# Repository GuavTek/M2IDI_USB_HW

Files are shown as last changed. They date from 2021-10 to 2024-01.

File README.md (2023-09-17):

This eurorack module connects MIDI over USB with the internal MIDI bus, and will work in both USB device and host modes. It also offers stereo audio streaming into and out from the rack when running in device mode. 
View this project on [CADLAB.io](https://cadlab.io/project/25232) to see renders of schematics and PCBs, as well as current issues. 

<h2> A part of the M2IDI prototypes </h2>

<p>
The code for this module can be found on  
<a href="https://github.com/GuavTek/M2IDI_USB">
			  GitHub
		  </a>
</p>

<p> 
More info on the M2IDI system can be found on the 
<a href="https://hackaday.io/project/182092-modular-midi">
			  Hackaday project page
		  </a>

</p>

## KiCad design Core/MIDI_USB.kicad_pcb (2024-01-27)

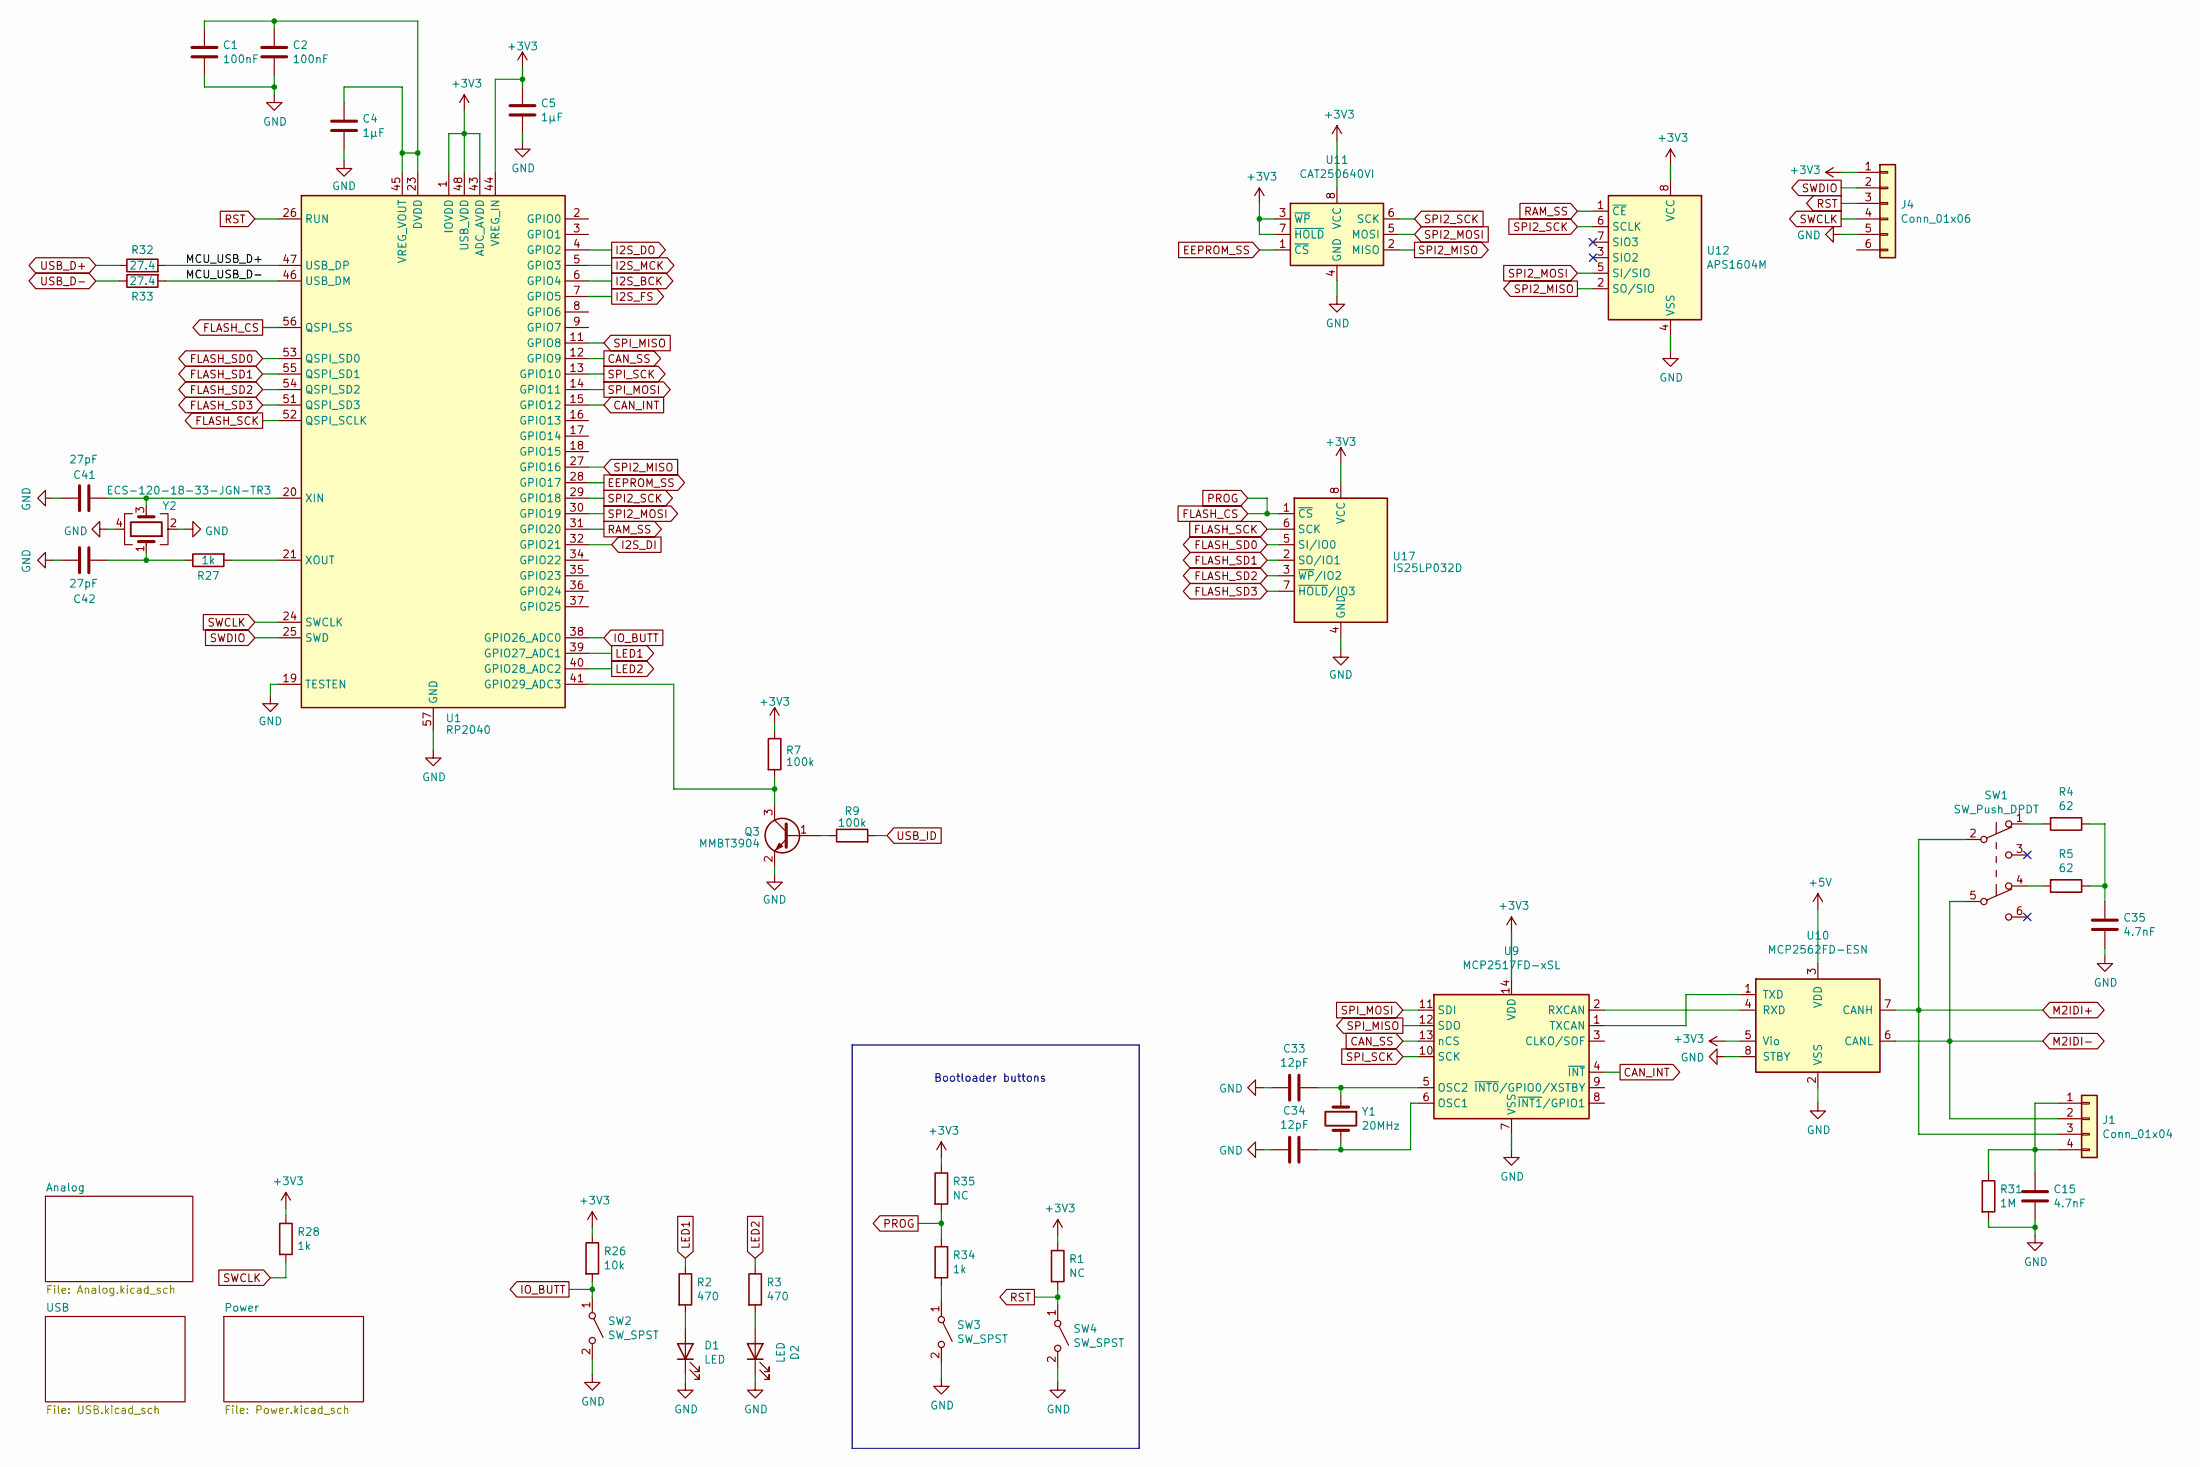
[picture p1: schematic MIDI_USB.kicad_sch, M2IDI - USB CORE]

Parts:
C1, C2: 100nF; C_0603_1608Metric
C4, C5: 1µF; C_0603_1608Metric
C15, C35: 4.7nF; C_0603_1608Metric
C33, C34: 12pF; C_0603_1608Metric
C41, C42: 27pF; C_0603_1608Metric
D1: LED; LED_D3.0mm_Horizontal_O1.27mm_Z2.0mm
D2: LED; LED_D3.0mm_Horizontal_O3.81mm_Z2.0mm
J1: Conn_01x04; MicroMatch_04_Angled
J4: Conn_01x06; PinHeader_2x03_P2.54mm_Vertical_SMD
Q3: MMBT3904; SOT-23
R1, R35: NC; R_0603_1608Metric
R2, R3: 470; R_0603_1608Metric
R4, R5: 62; R_0805_2012Metric
R7, R9: 100k; R_0603_1608Metric
R26: 10k; R_0603_1608Metric
R27, R28, R34: 1k; R_0603_1608Metric
R31: 1M; R_0603_1608Metric
R32, R33: 27.4; R_0603_1608Metric
SW1: SW_Push_DPDT; SlideDPDT_JS202011
SW2: SW_SPST; SW_Tactile_SPST_Angled_PTS645Vx58-2LFS
SW3, SW4: SW_SPST; SW_SPST_B3U-1000P
U1: RP2040; QFN-56-1EP_7x7mm_P0.4mm_EP3.2x3.2mm
U9: MCP2517FD-xSL; SOIC-14_3.9x8.7mm_P1.27mm
U10: MCP2562FD-ESN; SOIC-8_3.9x4.9mm_P1.27mm
U11: CAT250640VI; SOIC-8_3.9x4.9mm_P1.27mm
U12: APS1604M; SOIC-8_3.9x4.9mm_P1.27mm
U17: IS25LP032D; SOIC-8_3.9x4.9mm_P1.27mm
Y1: 20MHz; Crystal_2pin_2.0x2.5mm
Y2: ECS-120-18-33-JGN-TR3; Crystal_SMD_3225-4Pin_3.2x2.5mm_HandSoldering

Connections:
+3V3: C5.1, J4.1, R1.1, R7.1, R26.1, R28.1, R35.1, U1.1 (IOVDD), U1.10 (IOVDD), U1.22 (IOVDD), U1.33 (IOVDD), U1.42 (IOVDD), U1.43 (ADC_AVDD), U1.44 (VREG_IN), U1.48 (USB_VDD), U1.49 (IOVDD), U9.14 (VDD), U10.5 (Vio), U11.3 (~WP), U11.7 (~HOLD), U11.8 (VCC), U12.8 (VCC); also elsewhere on the board
/MCU_USB_D+: R32.2, U1.47 (USB_DP); also elsewhere on the board
/MCU_USB_D-: R33.2, U1.46 (USB_DM)
CAN_INT: U1.15 (GPIO12), U9.4 (~INT)
CAN_SS: U1.12 (GPIO9), U9.13 (nCS)
EEPROM_SS: U1.28 (GPIO17), U11.1 (~CS)
FLASH_CS: R34.1, R35.2, U1.56 (QSPI_SS); also elsewhere on the board
FLASH_SCK: U1.52 (QSPI_SCLK); also elsewhere on the board
FLASH_SD0: U1.53 (QSPI_SD0); also elsewhere on the board
FLASH_SD1: U1.55 (QSPI_SD1); also elsewhere on the board
FLASH_SD2: U1.54 (QSPI_SD2); also elsewhere on the board
FLASH_SD3: U1.51 (QSPI_SD3); also elsewhere on the board
I2S_BCK: U1.6 (GPIO4); also elsewhere on the board
I2S_DI: U1.32 (GPIO21); also elsewhere on the board
I2S_DO: U1.4 (GPIO2); also elsewhere on the board
I2S_FS: U1.7 (GPIO5); also elsewhere on the board
I2S_MCK: U1.5 (GPIO3); also elsewhere on the board
IO_BUTT: R26.2, SW2.1 (A), U1.38 (GPIO26_ADC0)
LED1: R2.1, U1.39 (GPIO27_ADC1)
LED2: R3.1, U1.40 (GPIO28_ADC2)
M2IDI+: J1.3, SW1.2 (B), U10.7 (CANH)
M2IDI-: J1.2, SW1.5 (B), U10.6 (CANL)
unnamed: C35.1, R4.1, R5.1
unnamed: C42.1, R27.1, Y2.1
unnamed: D1.2 (A), R2.2
unnamed: D2.2 (A), R3.2
unnamed: C15.1, J1.1, J1.4, R31.1
unnamed: Q3.1 (B), R9.1
unnamed: Q3.3 (C), R7.2, U1.41 (GPIO29_ADC3)
unnamed: R4.2, SW1.1 (A)
unnamed: R5.2, SW1.4 (A)
unnamed: R34.2, SW3.1 (A)
unnamed: C1.1, C2.1, C4.1, U1.23 (DVDD), U1.45 (VREG_VOUT), U1.50 (DVDD)
unnamed: C41.1, U1.20 (XIN), Y2.3
unnamed: R27.2, U1.21 (XOUT)
unnamed: C34.1, U9.6 (OSC1), Y1.2
unnamed: C33.1, U9.5 (OSC2), Y1.1
unnamed: U9.2 (RXCAN), U10.4 (RXD)
unnamed: U9.1 (TXCAN), U10.1 (TXD)
RAM_SS: U1.31 (GPIO20), U12.1 (~CE)
RST: J4.3, R1.2, SW4.1 (A), U1.26 (RUN)
SPI2_MISO: U1.27 (GPIO16), U11.2 (MISO), U12.2 (SO/SIO)
SPI2_MOSI: U1.30 (GPIO19), U11.5 (MOSI), U12.5 (SI/SIO)
SPI2_SCK: U1.29 (GPIO18), U11.6 (SCK), U12.6 (SCLK)
SPI_MISO: U1.11 (GPIO8), U9.12 (SDO)
SPI_MOSI: U1.14 (GPIO11), U9.11 (SDI)
SPI_SCK: U1.13 (GPIO10), U9.10 (SCK)
SWCLK: J4.4, R28.2, U1.24 (SWCLK)
SWDIO: J4.2, U1.25 (SWD)
USB_D-: R33.1; also elsewhere on the board

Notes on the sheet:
Bootloader buttons

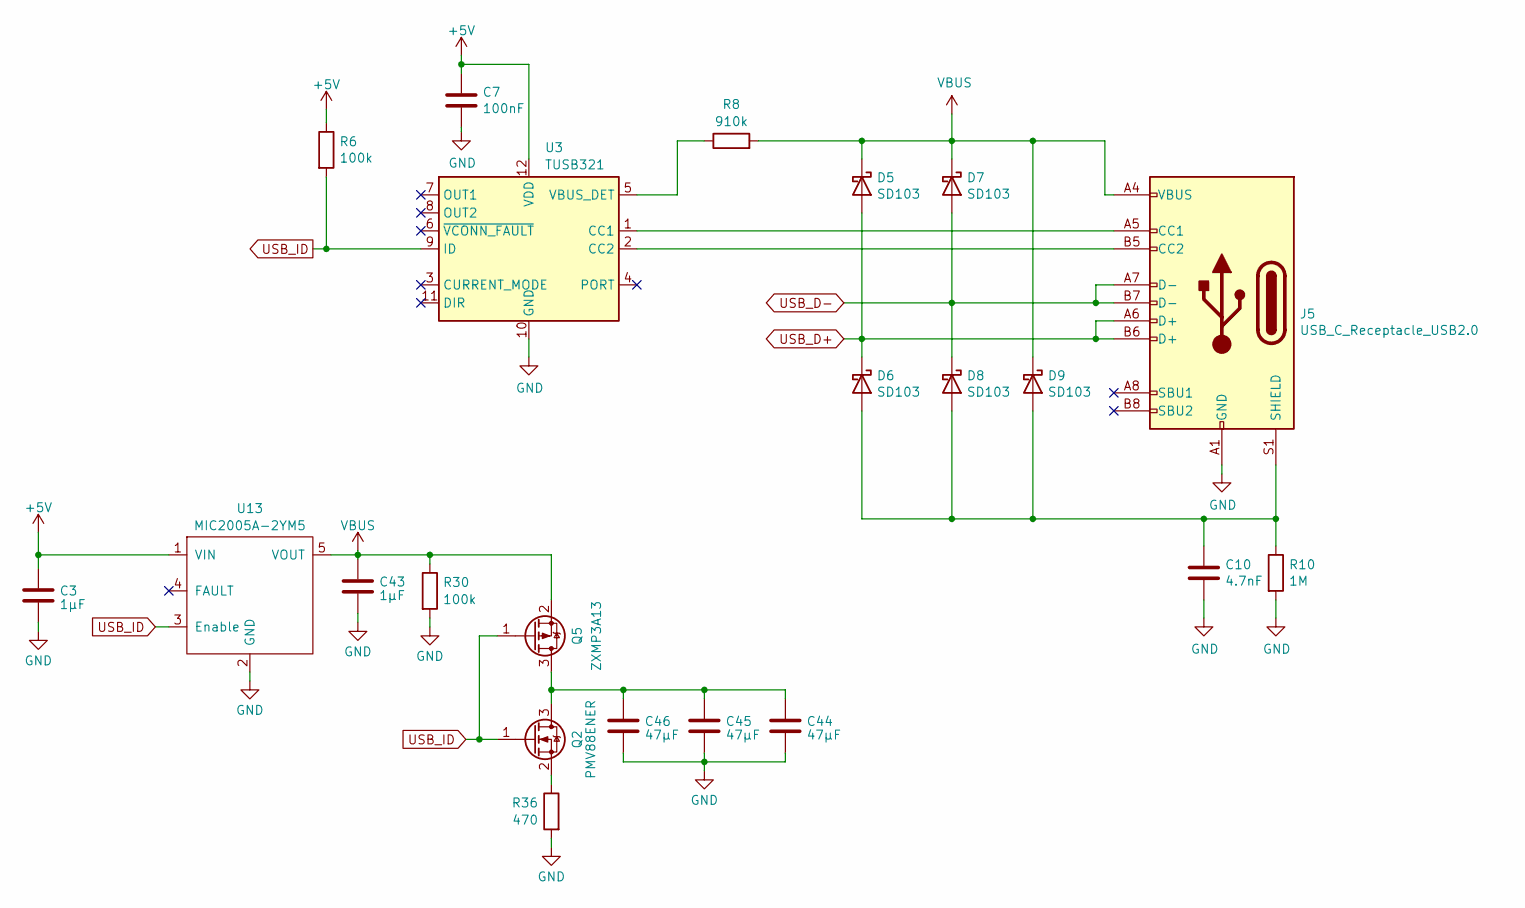
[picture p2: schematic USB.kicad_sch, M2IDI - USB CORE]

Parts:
C3, C43: 1µF; C_0603_1608Metric
C7: 100nF; C_0603_1608Metric
C10: 4.7nF; C_0603_1608Metric
C44, C45, C46: 47µF; C_1210_3225Metric
D5, D6, D7, D8, D9: SD103; D_SOD-323_HandSoldering
J5: USB_C_Receptacle_USB2.0; USB_C_Receptacle_HRO_TYPE-C-31-M-12
Q2: PMV88ENER; SOT-23
Q5: ZXMP3A13; SOT-23
R6, R30: 100k; R_0603_1608Metric
R8: 910k; R_0603_1608Metric
R10: 1M; R_0603_1608Metric
R36: 470; R_0603_1608Metric
U3: TUSB321; Texas_X2QFN-12_1.6x1.6mm_P0.4mm
U13: MIC2005A-2YM5; SOT-23-5

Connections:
unnamed: C10.1, D6.2 (A), D8.2 (A), D9.2 (A), J5.S1 (SHIELD), R10.1
unnamed: J5.A5 (CC1), U3.1 (CC1)
unnamed: J5.B5 (CC2), U3.2 (CC2)
unnamed: R8.1, U3.5 (VBUS_DET)
USB_D+: D5.2 (A), D6.1 (K), J5.A6 (D+), J5.B6 (D+); also elsewhere on the board
USB_D-: D7.2 (A), D8.1 (K), J5.A7 (D-), J5.B7 (D-); also elsewhere on the board

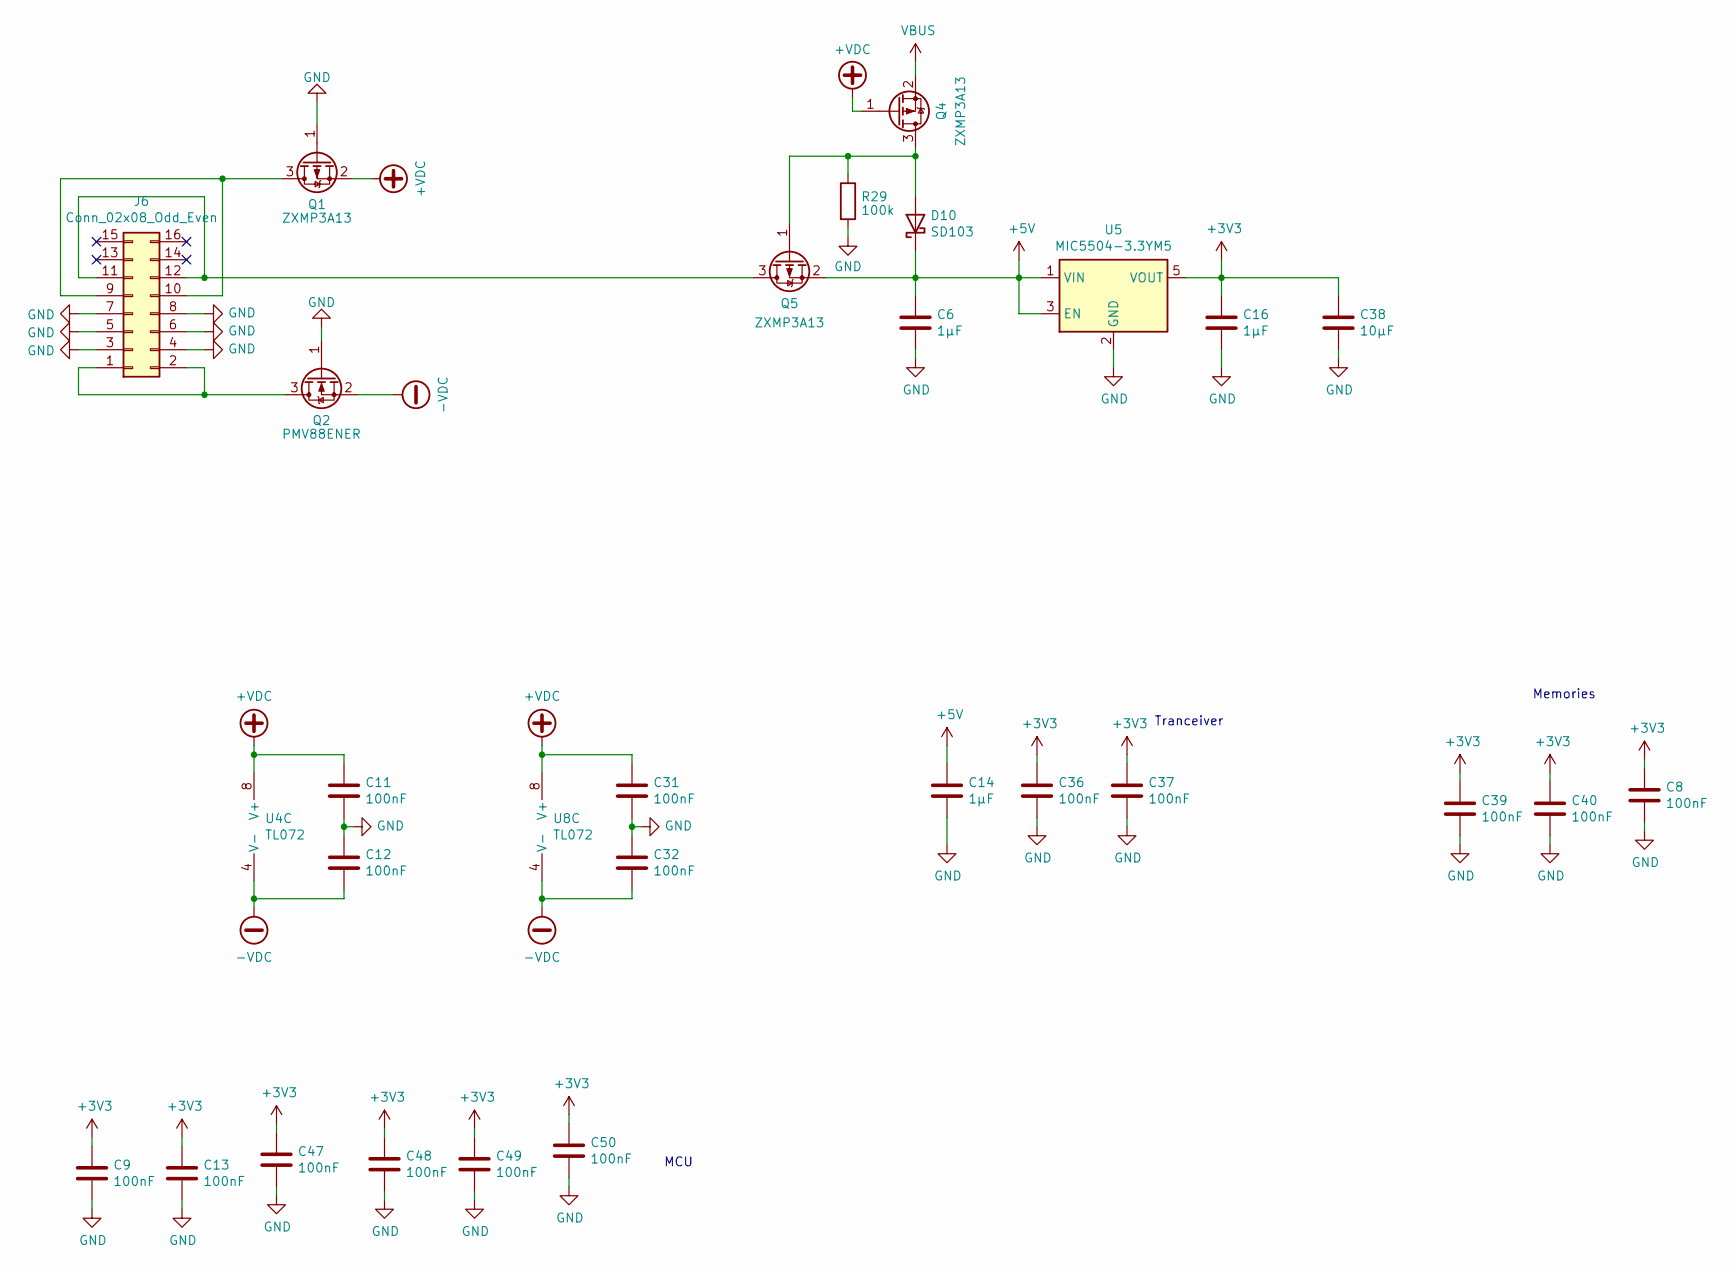
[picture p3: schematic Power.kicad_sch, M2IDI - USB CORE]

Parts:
C6, C14, C16: 1µF; C_0603_1608Metric
C8, C9, C11, C12, C13, C31, C32, C36, C37, C39, C40, C47, C48, C49, C50: 100nF; C_0603_1608Metric
C38: 10µF; C_0805_2012Metric
D10: SD103; D_SOD-323_HandSoldering
J6: Conn_02x08_Odd_Even; PinHeader_2x08_P2.54mm_Horizontal
Q1, Q4, Q5: ZXMP3A13; SOT-23
Q2: PMV88ENER; SOT-23
R29: 100k; R_0603_1608Metric
U4, U8: TL072; SO-8_3.9x4.9mm_P1.27mm
U5: MIC5504-3.3YM5; SOT-23-5

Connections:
+3V3: C8.1, C9.1, C13.1, C16.1, C36.1, C37.1, C38.1, C39.1, C40.1, C47.1, C48.1, C49.1, C50.1, U5.5 (VOUT); also elsewhere on the board
+VDC: C11.1, C31.1, Q1.2 (S), Q4.1 (G), U4.8 (V+), U8.8 (V+)
unnamed: J6.9, J6.10, Q1.3 (D)

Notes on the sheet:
Tranceiver
Memories
MCU

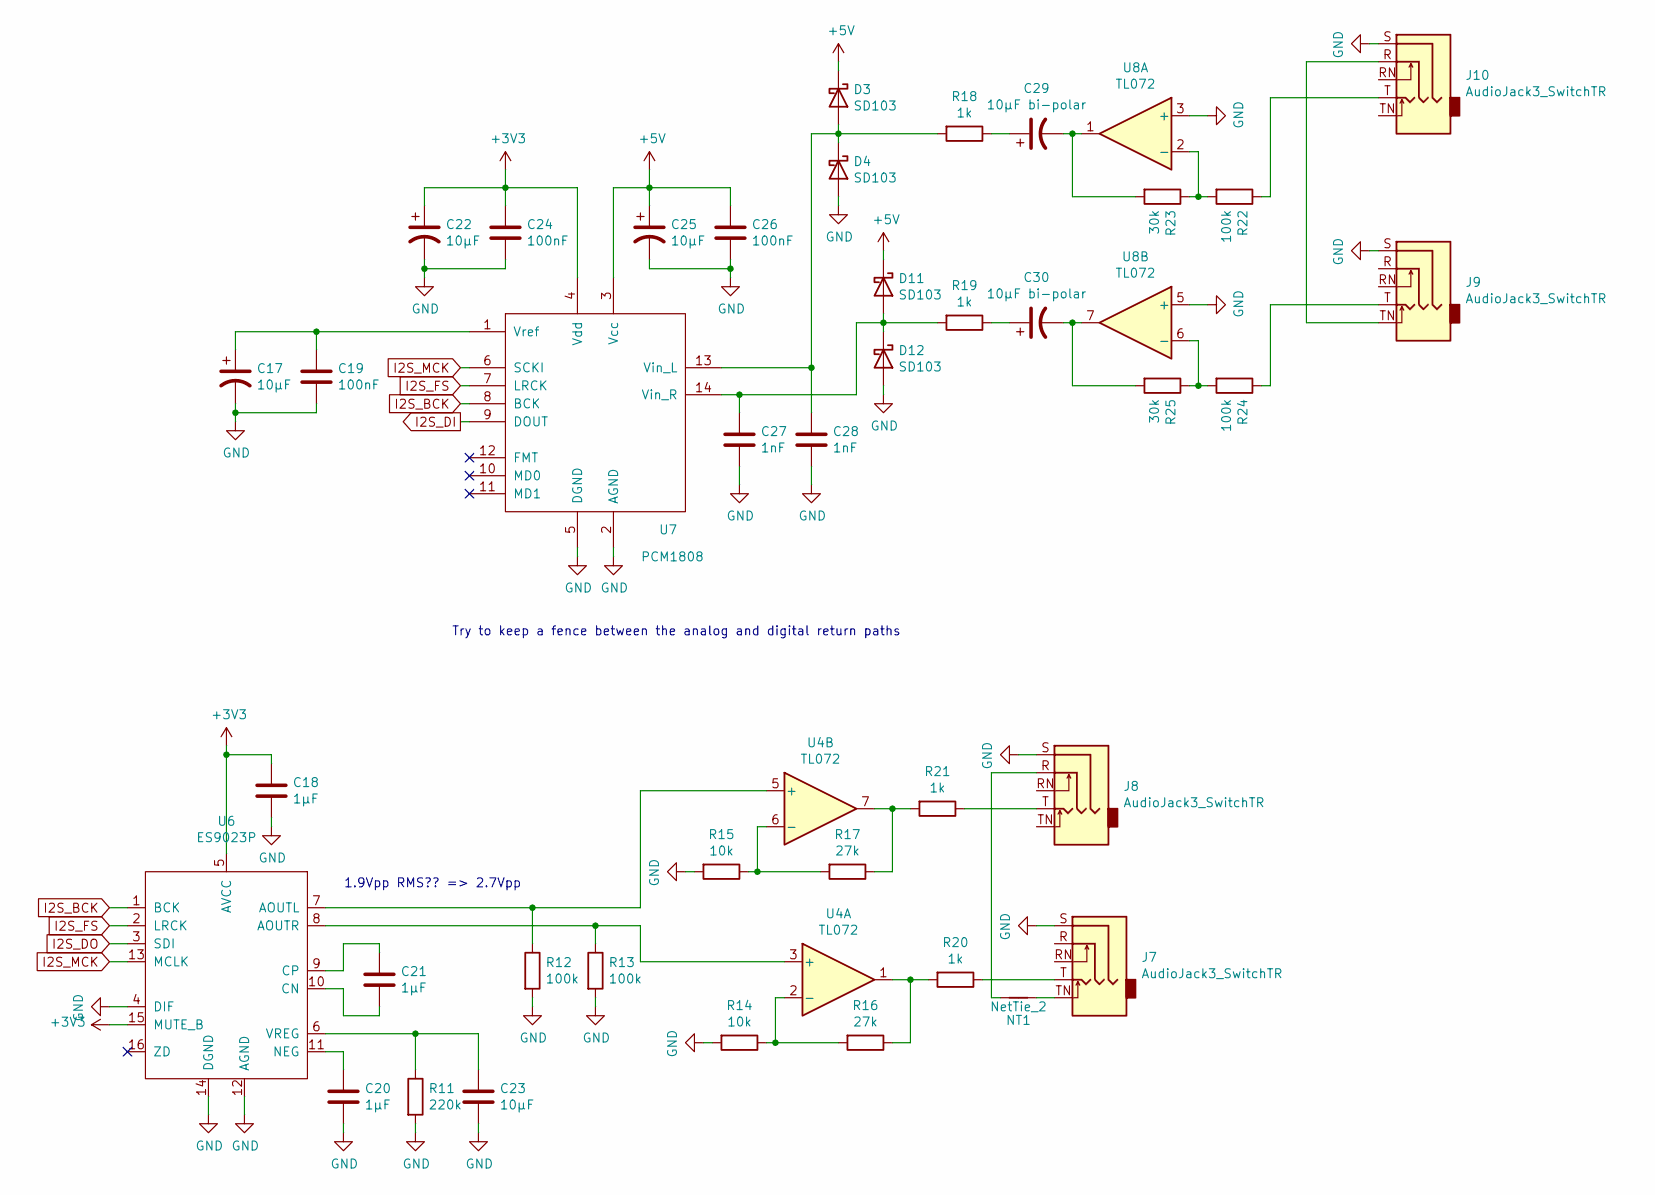
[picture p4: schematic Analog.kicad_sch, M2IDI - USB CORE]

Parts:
C17, C22, C23, C25: 10µF; C_0805_2012Metric
C18, C20, C21: 1µF; C_0603_1608Metric
C19, C24, C26: 100nF; C_0603_1608Metric
C27, C28: 1nF; C_0603_1608Metric
C29, C30: 10µF bi-polar; CP_Elec_5x5.8
D3, D4, D11, D12: SD103; D_SOD-323_HandSoldering
J7, J8, J9, J10: AudioJack3_SwitchTR; STX3100_Angled_3.5mm
NT1: NetTie_2; SolderJumper-2_P1.3mm_Open_RoundedPad1.0x1.5mm
R11: 220k; R_0603_1608Metric
R12, R13, R22, R24: 100k; R_0603_1608Metric
R14, R15: 10k; R_0603_1608Metric
R16, R17: 27k; R_0603_1608Metric
R18, R19, R20, R21: 1k; R_0603_1608Metric
R23, R25: 30k; R_0603_1608Metric
U4, U8: TL072; SO-8_3.9x4.9mm_P1.27mm
U6: ES9023P; SOIC-16_3.9x9.9mm_P1.27mm
U7: PCM1808; TSSOP-14_4.4x5mm_P0.65mm

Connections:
+3V3: C18.1, C22.1, C24.1, U6.5 (AVCC), U6.15 (MUTE_B), U7.4 (Vdd); also elsewhere on the board
I2S_BCK: U6.1 (BCK), U7.8 (BCK); also elsewhere on the board
I2S_DI: U7.9 (DOUT); also elsewhere on the board
I2S_DO: U6.3 (SDI); also elsewhere on the board
I2S_FS: U6.2 (LRCK), U7.7 (LRCK); also elsewhere on the board
I2S_MCK: U6.13 (MCLK), U7.6 (SCKI); also elsewhere on the board
unnamed: C29.1, R18.1
unnamed: C29.2, R23.2, U8.1
unnamed: C30.1, R19.1
unnamed: C30.2, R25.2, U8.7
unnamed: C28.1, D3.2 (A), D4.1 (K), R18.2, U7.13 (Vin_L)
unnamed: C27.1, D11.2 (A), D12.1 (K), R19.2, U7.14 (Vin_R)
unnamed: J7.T, R20.1
unnamed: J7.TN, NT1.1
unnamed: J8.R, NT1.2
unnamed: J8.T, R21.1
unnamed: J9.T, R24.1
unnamed: J9.TN, J10.R
unnamed: J10.T, R22.1
unnamed: R16.1, R20.2, U4.1
unnamed: R17.1, R21.2, U4.7
unnamed: R13.1, U4.3 (+), U6.8 (AOUTR)
unnamed: R14.1, R16.2, U4.2 (-)
unnamed: R12.1, U4.5 (+), U6.7 (AOUTL)
unnamed: R15.1, R17.2, U4.6 (-)
unnamed: C21.2, U6.10 (CN)
unnamed: C21.1, U6.9 (CP)
unnamed: C20.1, U6.11 (NEG)
unnamed: C23.1, R11.1, U6.6 (VREG)
unnamed: C17.1, C19.1, U7.1 (Vref)
unnamed: R22.2, R23.1, U8.2 (-)
unnamed: R24.2, R25.1, U8.6 (-)

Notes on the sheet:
1.9Vpp RMS?? => 2.7Vpp
Try to keep a fence between the analog and digital return paths

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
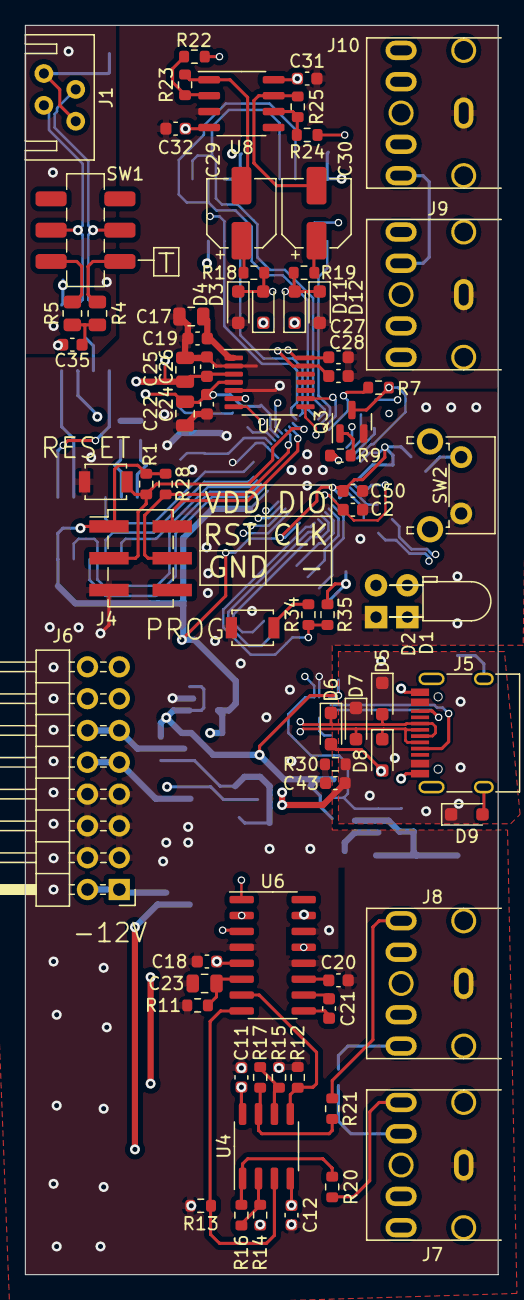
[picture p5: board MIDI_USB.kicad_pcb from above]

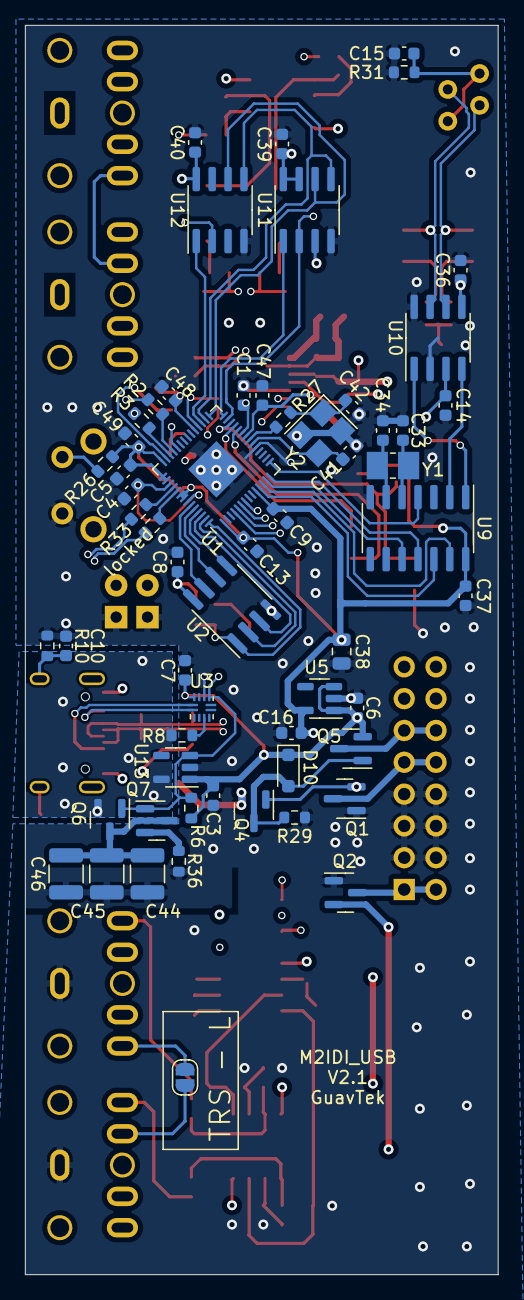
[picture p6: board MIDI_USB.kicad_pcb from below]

Board: 4 copper layers, 37.8 x 99.8 mm, 133 parts (59 on the bottom side), 93 nets.

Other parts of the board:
Q6: ZXMP3A13; SOT-23
Q7: PMV88ENER; SOT-23
U2: IS25LP032D; SOIC-8_3.9x4.9mm_P1.27mm
locked: 27.4; R_0603_1608Metric

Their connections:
+3V3: U2.8 (VCC); also elsewhere on the board
/MCU_USB_D+: locked.2; also elsewhere on the board
FLASH_CS: U2.1 (~CS); also elsewhere on the board
FLASH_SCK: U2.6 (SCK); also elsewhere on the board
FLASH_SD0: U2.5 (SI/IO0); also elsewhere on the board
FLASH_SD1: U2.2 (SO/IO1); also elsewhere on the board
FLASH_SD2: U2.3 (~WP/IO2); also elsewhere on the board
FLASH_SD3: U2.7 (~HOLD/IO3); also elsewhere on the board
USB_D+: locked.1; also elsewhere on the board

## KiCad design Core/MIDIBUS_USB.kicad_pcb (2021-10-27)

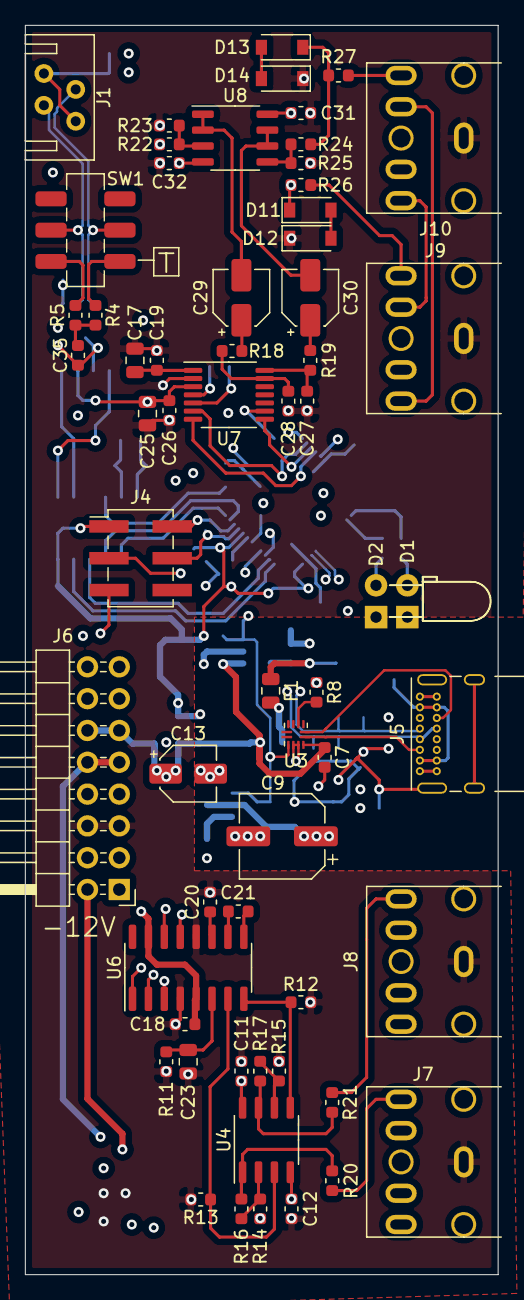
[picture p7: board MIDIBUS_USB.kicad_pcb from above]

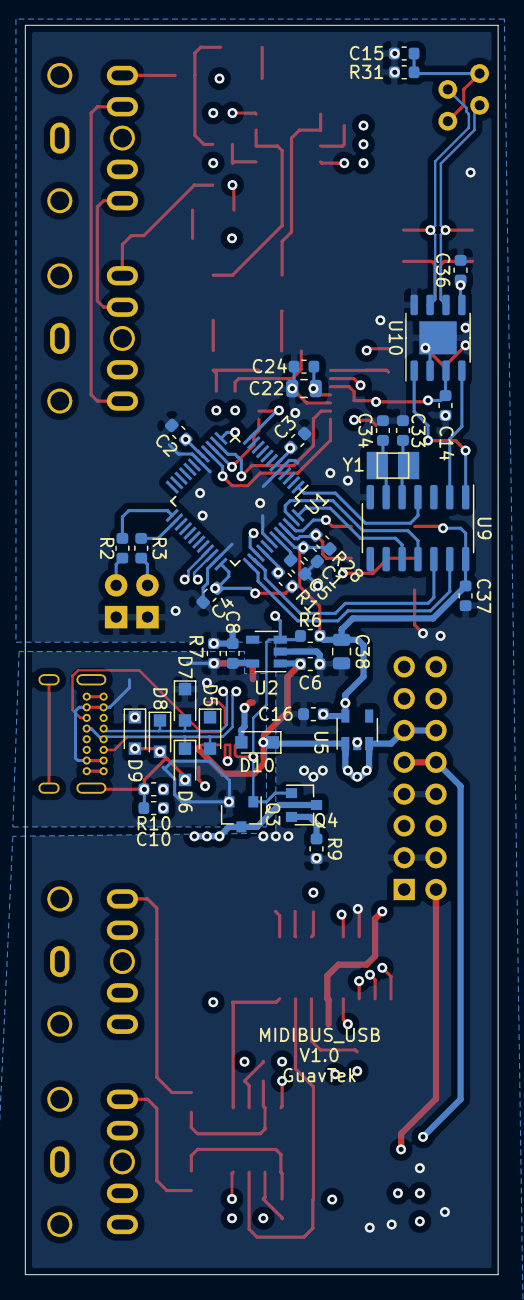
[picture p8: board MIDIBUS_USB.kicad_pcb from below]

Board: 4 copper layers, 37.8 x 99.8 mm, 102 parts (41 on the bottom side), 74 nets.

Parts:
C1, C2, C3, C4, C7, C11, C12, C19, C24, C26, C31, C32, C36, C37: 100nF; C_0603_1608Metric
C5, C6, C8, C14, C16, C18, C20, C21: 1µF; C_0603_1608Metric
C9: 120µF; CP_Elec_6.3x5.7
C10, C15: 4.7nF; C_0603_1608Metric
C13: 3.3µF; CP_Elec_4x5.4
C17, C22, C23, C25, C38: 10µF; C_0805_2012Metric
C27, C28: 1nF; C_0603_1608Metric
C29, C30: 1µF; CP_Elec_4x5.4
C33, C34: 15pF; C_0603_1608Metric
C35: 22nF; C_0603_1608Metric
D1: LED; LED_D3.0mm_Horizontal_O1.27mm_Z2.0mm
D2: LED; LED_D3.0mm_Horizontal_O3.81mm_Z2.0mm
D5, D6, D7, D8, D9, D10: SD103; D_SOD-323_HandSoldering
D11, D12, D13, D14: 5V6; D_SOD-123
F1: PSMF020X-2; Fuse_0805_2012Metric
J1: Conn_01x04; MicroMatch_04_Angled
J4: Conn_01x06; PinHeader_2x03_P2.54mm_Vertical_SMD
J5: USB_C_Receptacle_USB2.0; USB_C_Receptacle_GCT_USB4085_Slimmed
J6: Conn_02x08_Odd_Even; PinHeader_2x08_P2.54mm_Horizontal
J7, J8, J9, J10: AudioJack3_SwitchTR; STX3100_Angled_3.5mm
Q3: SQ2361; SOT-23
Q4: 2N7002; SOT-23
R1, R6, R14, R15, R28: 10k; R_0603_1608Metric
R2, R3, R9: 470; R_0603_1608Metric
R4, R5: 120; R_0603_1608Metric
R7, R12, R13, R22, R24: 100k; R_0603_1608Metric
R8: 910k; R_0603_1608Metric
R10, R31: 1M; R_0603_1608Metric
R11: 220k; R_0603_1608Metric
R16, R17: 42k; R_0603_1608Metric
R18, R19, R20, R21, R26, R27: 1k; R_0603_1608Metric
R23, R25: 30k; R_0603_1608Metric
SW1: SW_Push_DPDT; SlideDPDT_JS202011
U1: ATSAMD21G15B-A; TQFP-48_7x7mm_P0.5mm
U2: MIC2005-2YM5; SOT-23-5
U3: TUSB320; Texas_X2QFN-12_1.6x1.6mm_P0.4mm
U4, U8: TL072; SO-8_3.9x4.9mm_P1.27mm
U5: MIC5504-3.3YM5; SOT-23-5
U6: ES9023P; SOIC-16_3.9x9.9mm_P1.27mm
U7: PCM1808; TSSOP-14_4.4x5mm_P0.65mm
U9: MCP2517FD-xSL; SOIC-14_3.9x8.7mm_P1.27mm
U10: TLE9250V; Infineon_PG-DSO-8-27_3.9x4.9mm_EP2.65x3mm
Y1: 20MHz; Crystal_2pin_2.0x2.5mm

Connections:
+3V3: C1.1, C2.1, C3.1, C4.1, C16.1, C18.1, C22.1, C24.1, C36.1, C37.1, C38.1, J4.1, R1.1, R6.1, R28.1, U1.6, U1.17, U1.36, U1.44, U5.5, U6.5, U6.15, U7.4, U9.14, U10.5
+5V: C6.1, C7.1, C13.1, C14.1, C25.1, C26.1, D10.1, J6.11, J6.12, U2.1, U3.12, U5.1, U5.3, U7.3, U10.3
+VDC: C11.1, C31.1, J6.9, J6.10, U4.8, U8.8
-VDC: C12.2, C32.2, J6.1, J6.2, U4.4, U8.4
CAN_INT: U1.1, U9.4
GND: C1.2, C2.2, C3.2, C4.2, C5.2, C6.2, C7.2, C8.2, C9.2, C10.2, C13.2, C14.2, C15.2, C16.2, C22.2, C24.2, C33.2, C34.2, C35.2, C36.2, C37.2, C38.2, D1.1, D2.1, J4.5, J5.A1, J5.A12, J5.B1, J5.B12, J6.3, J6.4, J6.7, J6.8, R7.2, R9.2, R10.2, R31.2, U1.5, U1.18, U1.35, U1.42, U2.2, U3.10, U3.11, U5.2, U6.14, U7.5, U9.7, U10.2, U10.8, U10.9
GNDA: C11.2, C12.1, C17.2, C18.2, C19.2, C20.2, C23.2, C25.2, C26.2, C27.2, C28.2, C31.2, C32.1, D12.1, D14.1, J6.5, J6.6, J7.S, J8.S, J9.S, J10.S, R11.2, R12.2, R13.2, R14.2, R15.2, R23.2, R25.2, U6.4, U6.12, U7.2
I2S_DI: U1.12, U7.9
I2S_DO: U1.13, U6.3
I2S_FS: U1.16, U6.2, U7.7
I2S_MCK: U1.14, U6.13, U7.6
I2S_SCK: U1.15, U6.1, U7.8
LED1: R2.1, U1.25
LED2: R3.1, U1.26
MIDIBUS+: J1.3, SW1.2, U10.7
MIDIBUS-: J1.2, SW1.5, U10.6
unnamed: C5.1, U1.43
unnamed: C9.1, Q3.3, Q4.3
unnamed: C10.1, D6.2, D8.2, D9.2, J5.S1, R10.1
unnamed: C15.1, J1.1, J1.4, R31.1
unnamed: C17.1, C19.1, U7.1
unnamed: C20.1, U6.11
unnamed: C21.1, U6.9
unnamed: C21.2, U6.10
unnamed: C23.1, R11.1, U6.6
unnamed: C27.1, R19.2, U7.14
unnamed: C28.1, R18.2, U7.13
unnamed: C29.1, R18.1
unnamed: C29.2, U8.1, U8.2
unnamed: C30.1, R19.1
unnamed: C30.2, U8.6, U8.7
unnamed: C33.1, U9.5, Y1.1
unnamed: C34.1, U9.6, Y1.2
unnamed: C35.1, R4.1, R5.1
unnamed: D1.2, R2.2
unnamed: D2.2, R3.2
unnamed: D10.2, F1.2
unnamed: D11.1, R22.1, R26.2
unnamed: D11.2, D12.2
unnamed: D13.1, R24.1, R27.2
unnamed: D13.2, D14.2
unnamed: J5.A5, U3.1
unnamed: J5.B5, U3.2
unnamed: J7.T, R20.1
unnamed: J8.T, R21.1
unnamed: J9.T, R26.1
unnamed: J9.TN, J10.R
unnamed: J10.T, R27.1
unnamed: J9.R, J10.TN
unnamed: Q4.2, R9.1
unnamed: R4.2, SW1.1
unnamed: R5.2, SW1.4
unnamed: R8.2, U3.4
unnamed: R12.1, U4.5, U6.8
unnamed: R13.1, U4.3, U6.7
unnamed: R14.1, R16.2, U4.2
unnamed: R15.1, R17.2, U4.6
unnamed: R16.1, R20.2, U4.1
unnamed: R17.1, R21.2, U4.7
unnamed: R22.2, R23.1, U8.3
unnamed: R24.2, R25.1, U8.5
unnamed: U9.1, U10.1
unnamed: U9.2, U10.4
RST: J4.3, R1.2, U1.40
SPI_MISO: U1.38, U9.12
SPI_MOSI: U1.47, U9.11
SPI_SCK: U1.48, U9.10
SPI_SS: U1.37, U9.13
SWCLK: J4.4, R28.2, U1.45
SWDIO: J4.2, U1.46
USB_D+: D5.2, D6.1, J5.A6, J5.B6, U1.34
USB_D-: D7.2, D8.1, J5.A7, J5.B7, U1.33
USB_ID: Q3.1, Q4.1, R6.2, U1.39, U2.3, U3.9
VBUS: C8.1, D5.1, D7.1, D9.1, F1.1, J5.A4, J5.A9, J5.B4, J5.B9, Q3.2, R7.1, R8.1, U2.5

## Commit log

2021-10-27 Add all the files
    [Analog.sch, MIDI_USB.kicad_pcb, MIDI_USB.sch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]
2021-10-27 Update filenames
    [MIDIBUS_USB.kicad_pcb, MIDIBUS_USB.sch, MIDIBUS_USB_Front.kicad_pcb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]
2022-02-17 Adjust filenames
    [MIDI_USB.kicad_pcb, MIDI_USB.sch, MIDI_USB_Front.kicad_pcb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]
2022-02-18 Fix symbols
    [Analog.sch, MIDI_USB.kicad_pcb, USB.sch]
2022-02-18 Include symbol library
    [Analog.sch, USB.sch]
2022-02-19 Add custom footprints
    [Analog.sch, MIDI_USB.kicad_pcb, MIDI_USB.sch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]
2022-02-19 Fix part number
    [MIDI_USB.sch]
2022-06-30 Reduce distortion in ADC circuit
    [Analog.sch]
2022-06-30 Change to SMD USB connector
    [USB.sch]
2022-06-30 Add external EEPROM and RAM
    [MIDI_USB.sch, Power.sch]
2022-06-30 Add IO and bootloader buttons
    [Analog.sch, MIDI_USB.sch, Power.sch]
2022-07-02 Fix DAC amplitude
    [Analog.sch]
2022-07-02 Add external RTC oscillator
    [MIDI_USB.sch]
2023-04-08 Update front panel
    [MIDI_USB_Front.kicad_pcb, MIDI_USB_Front.kicad_sch, MIDI_USB_Front.sch]
2023-06-10 Update to v1.1
    [Analog.kicad_sch, MIDI_USB.kicad_pcb, MIDI_USB.kicad_sch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]
2023-06-11 Update front panel layout
    [MIDI_USB_Front.kicad_pcb, MIDI_USB_Front.kicad_sch]
2023-06-11 Minor fixes
    [Analog.kicad_sch, MIDI_USB.kicad_pcb]
2023-06-13 Adjust vias
    [MIDI_USB.kicad_pcb, Power.kicad_sch]
2023-06-18 Switch to RP2040
    [Analog.kicad_sch, MIDI_USB.kicad_pcb, MIDI_USB.kicad_sch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]
2023-06-18 Update metadata
    [Analog.kicad_sch, MIDI_USB.kicad_pcb, MIDI_USB.kicad_sch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]
2023-06-19 Add optional solder bridge++
    [Analog.kicad_sch, MIDI_USB.kicad_pcb, Power.kicad_sch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]
2023-07-09 Change CAN tranceiver to MCP2562
    [MIDI_USB.kicad_pcb, MIDI_USB.kicad_sch, USB.kicad_sch]
2023-07-09 Fix crystal footprint
    [MIDI_USB.kicad_pcb]
2023-07-12 Re-arrange USB components
    [MIDI_USB.kicad_pcb, MIDI_USB_Front.kicad_pcb]
2023-07-14 Adjust 5V power protection
    [MIDI_USB.kicad_pcb, MIDI_USB_Front.kicad_pcb, Power.kicad_sch]
2023-09-01 Finalize module
    [MIDI_USB.kicad_pcb, MIDI_USB.kicad_sch]
2023-09-10 Remove old kicad files
    [Analog.sch, MIDI_USB.sch, Power.sch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]
2023-09-17 Increase button hole size
    [MIDI_USB_Front.kicad_pcb]
2023-09-17 Re-add Custom_FP library
    [MIDI_USB.kicad_pcb, MIDI_USB_Front.kicad_pcb]
2024-01-27 Change USB id chips to TUSB321 and MID2005
    [Analog.kicad_sch, MIDI_USB.kicad_pcb, MIDI_USB.kicad_sch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]
2024-03-31 Switch from CC license to CERN open hardware
